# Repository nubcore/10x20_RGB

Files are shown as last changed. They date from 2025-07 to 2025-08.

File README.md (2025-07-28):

# 10x20_LED_screen
hardware design files and software applications for an esp32c3 + 200 "smart LEDs"  project.

## General

The PCB contains an ESP32-C3, 4 buttons and 200 ws2812B-like "smart LED" components that each contain three 256 level PWM controllers to drive the Red, Green and Blue LED channels. This means that each LED can theoretically display 2^24 colour combinations. The LEDs are supplied with the necessary data using a serial protocol, and are all connected in series in a single "string", so to drive all the LEDs, the ESP32-C3 must send 200 * 24 = 4800 bits of data. The LEDs need this data to be supplied at a net rate of 800,000 bits per second.
The actual low-level protocol used to transmit the data to the LEDs is as follows:

- ALL bits for a string of LEDs must be transmitted as a continuous stream immediately after a "reset pulse"
- A "0"-bit is transmitted as a 4 us high level, followed by an 8 us low level
- A "1"-bit is transmitted as an 8 us high level, followed by a 4 us low level
- After all bits have been transmitted, a 50 us low level serves as a "reset pulse"

This could be done using "bit-banging", but then the ESP can do little else aside. Alternatively, one can put one of the ESP32-C3's hardware peripherals to "alternative use".

## Hardware

The "hardware" folder contains the schematic diagram and KiCAD source files for this project.

__PLEASE NOTE THE FOLLOWING:__

This Do-It-Yourself project comes without any guarantee whatsoever.

5V Power should always be supplied to the LED portion DIRECTLY, NOT via the USB connector on the ESP32-C3 module.

It is, however, possible to supply the ESP32-C3 from the LED portion power supply by fitting a 0 Ohm resistor to R2. R2 should ONLY be fitted if you want to power the ESP32-C3 from the power supply connected to the LED portion, and it is then recommended to completely disconnect the USB cable and remove the USB connector from the ESP32-C3 module to prevent accidentally drawing power for the LED portion through the USB cable connected to the ESP32-C3 module.

Attempting to supply power through the USB connecter to the ESP32-C3 AND the LED portion may lead to damage to the ESP32-C3 module AND/OR to the USB power source. The LED portion alone can draw in excess of 1.5 A, and the ESP32-C3 module PCB traces and components are NOT rated for this. The LED portion does NOT properly negotiate its power draw with the power source by itself, and while the ESP32-C3 might be able to take on this task, there is no guarantee (given that users can run their own code on the ESP32-C3) that it will.

__TL;DR: Do not fit R2 unless you know what you are doing and willing to bear any and all consequences.__

## Software

The "software" folder contains some self-contained example Arduino applications. Two of these applications demonstrate the use of ESP32-C3's hardware peripherals to drive the display
.
### Driving the display with the "RMT" (remote control) perhipheral

The ledscreentest1 example demonstrates the use of the "RMT" perhipheral.Can generate very accurately timed signals, but has enormous memory overhead: it requires 32 times more storage than there is raw data to be sent to the LEDs. 24 bits to be sent to each LED requires 768 bits of memory. Every RGB byte translates to 8 32 bit word accesses. This method uses DMA (Direct memory access) to relieve the processor of these duties: The processor just needs to prepare a block of data and then start the transfer.

### Driving the display with the "SPI" (synchronous serial port) perhipheral 

The ledscreentest2 example demionstrates the use of the "SPI" perhipheral. Signals are less accuratly timed, but do actually work with the types of LEDs tested so far. Overhead is much lower than for the "RMT" method: it requires 4 times more storage than there is raw data to be sent to the LEDs. 24 bits to be sent to each LED requires 96 bits of memory. Moreover, as every (RGB) byte access becomes a single 32 bit word access, processor overhead is relatively limited. This method uses DMA (Direct memory access) to relieve the processor of these duties: The processor just needs to prepare a block of data and then start the transfer.

### "Famous-Falling-Block-Game"-tris

The blocktris example game uses 6 combinations of 2 buttons that are simultaneously pressed to control a falling block:

- start game
- move left
- move right
- turn clockwise
- turn counter-clockwise
- drop

Objective of the game is to score points by completely filling as many rows on the board as possible: 1 row = 1 point, 2 rows = 4 points, 3 rows = 9 points and 4 rows = 16 points. Completed rows are removed from the board, and the game ends when there is no more room for a new piece to spawn.

If you fill in the login credentials of an access point, the module will try to communicate a (global) high-score with a server.

### "Floppy brick"

Fly a brick, avoiding increasingly difficult obstacles along it's path by commanding it to flop using the "flop" button.

## Prerequisites

As Espressif regulary makes breaking changes to their API, it is important that you use the __correct version of the Espressif framework for Arduino: 3.1.3__

After you have installed the Espressif board manager package, you can __select the "ESP32-C3 Dev-module"__, which is compatible with the ESP32-C3 "super-mini" module that is usedin this project.

Please make sure that you have __set the option "USB CDC enable on boot" to "enabled"__ (Arduino tools menu), and that you have selected the correct serial device.

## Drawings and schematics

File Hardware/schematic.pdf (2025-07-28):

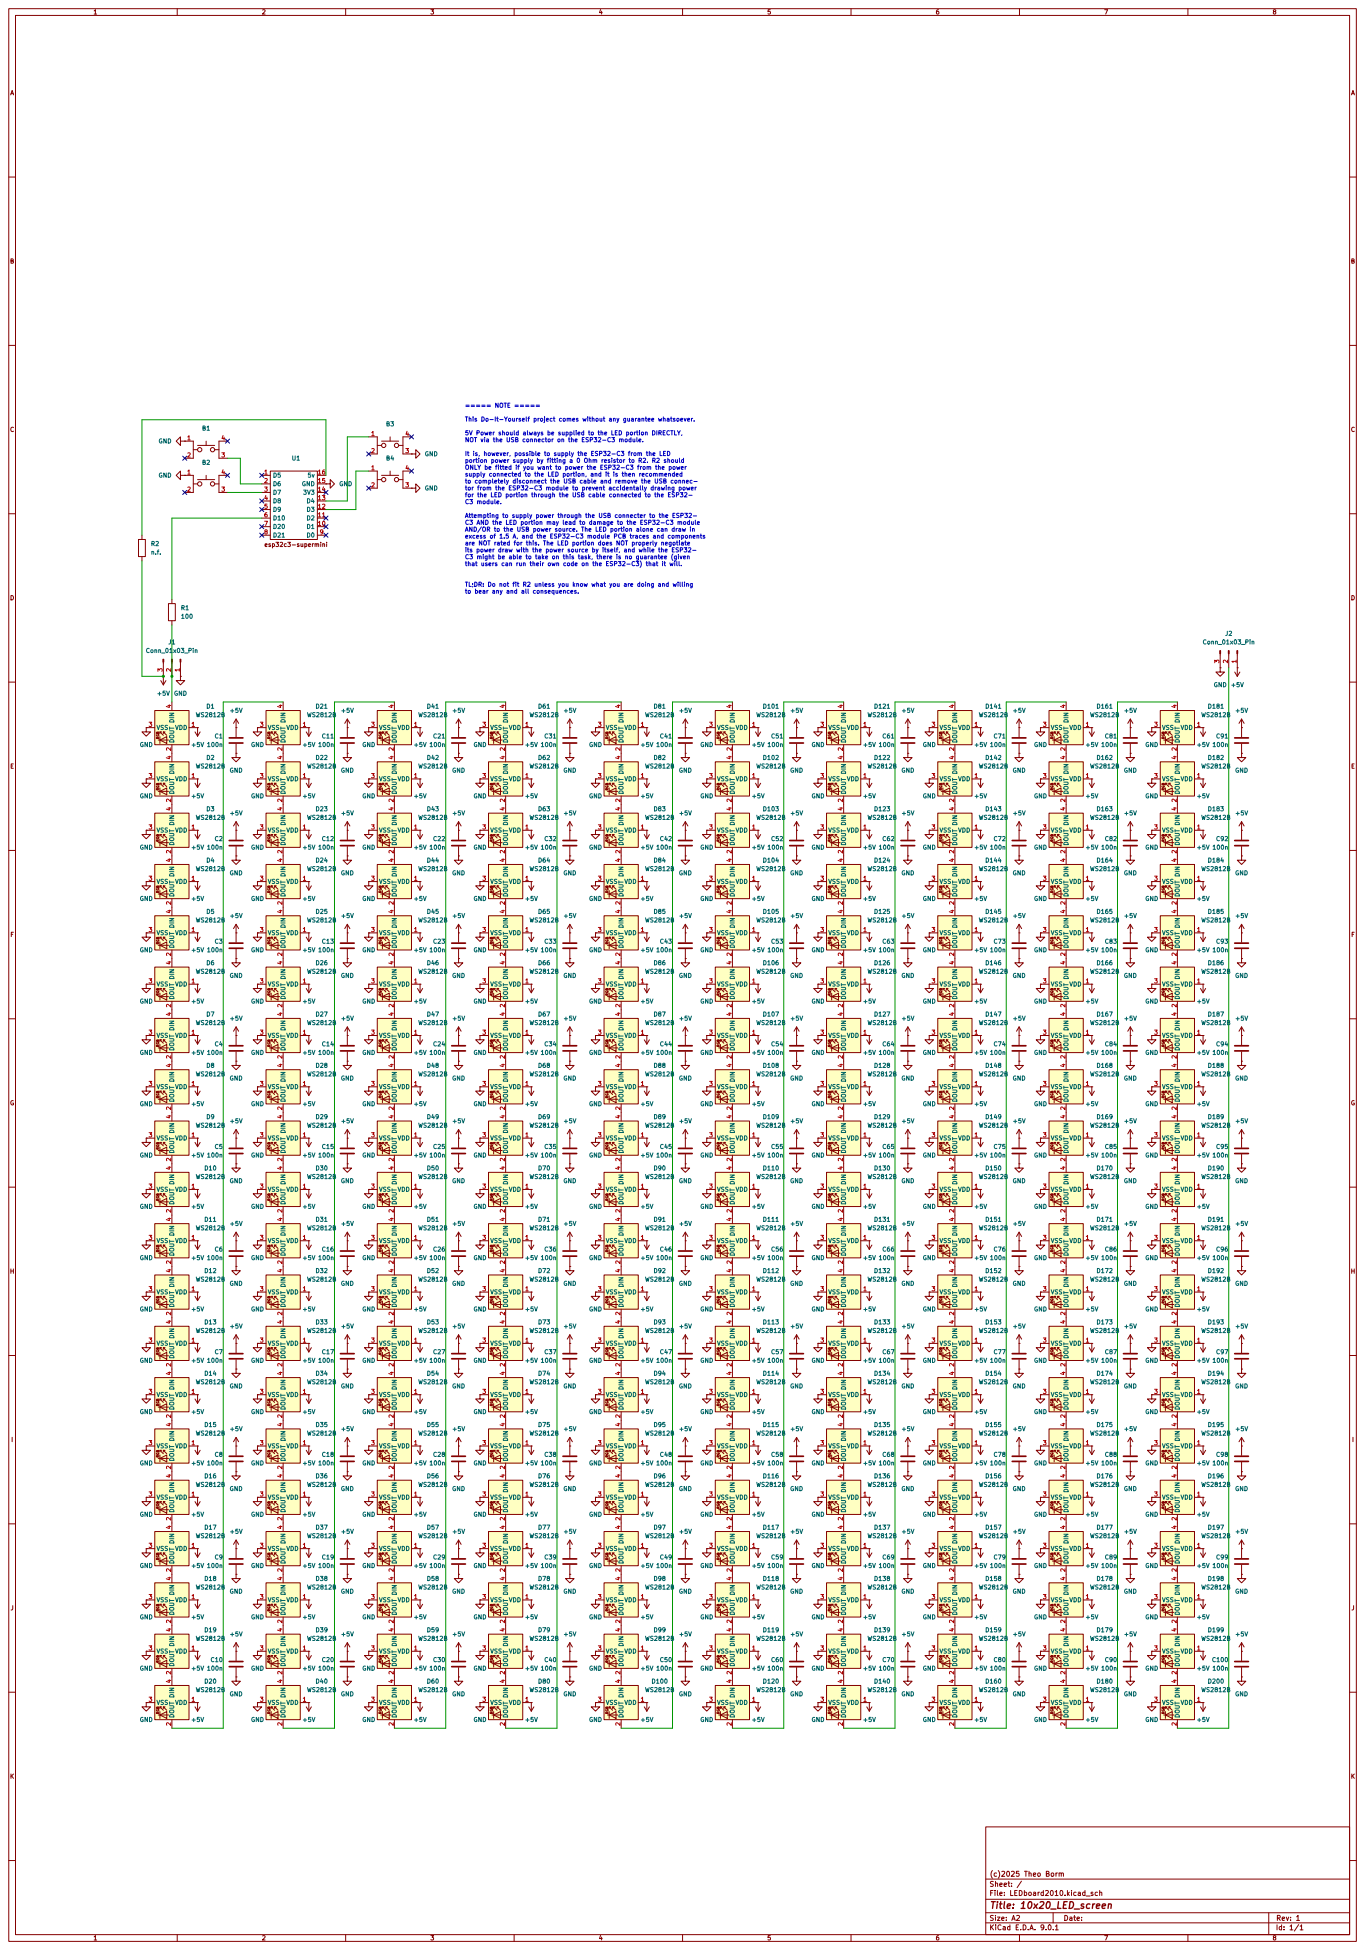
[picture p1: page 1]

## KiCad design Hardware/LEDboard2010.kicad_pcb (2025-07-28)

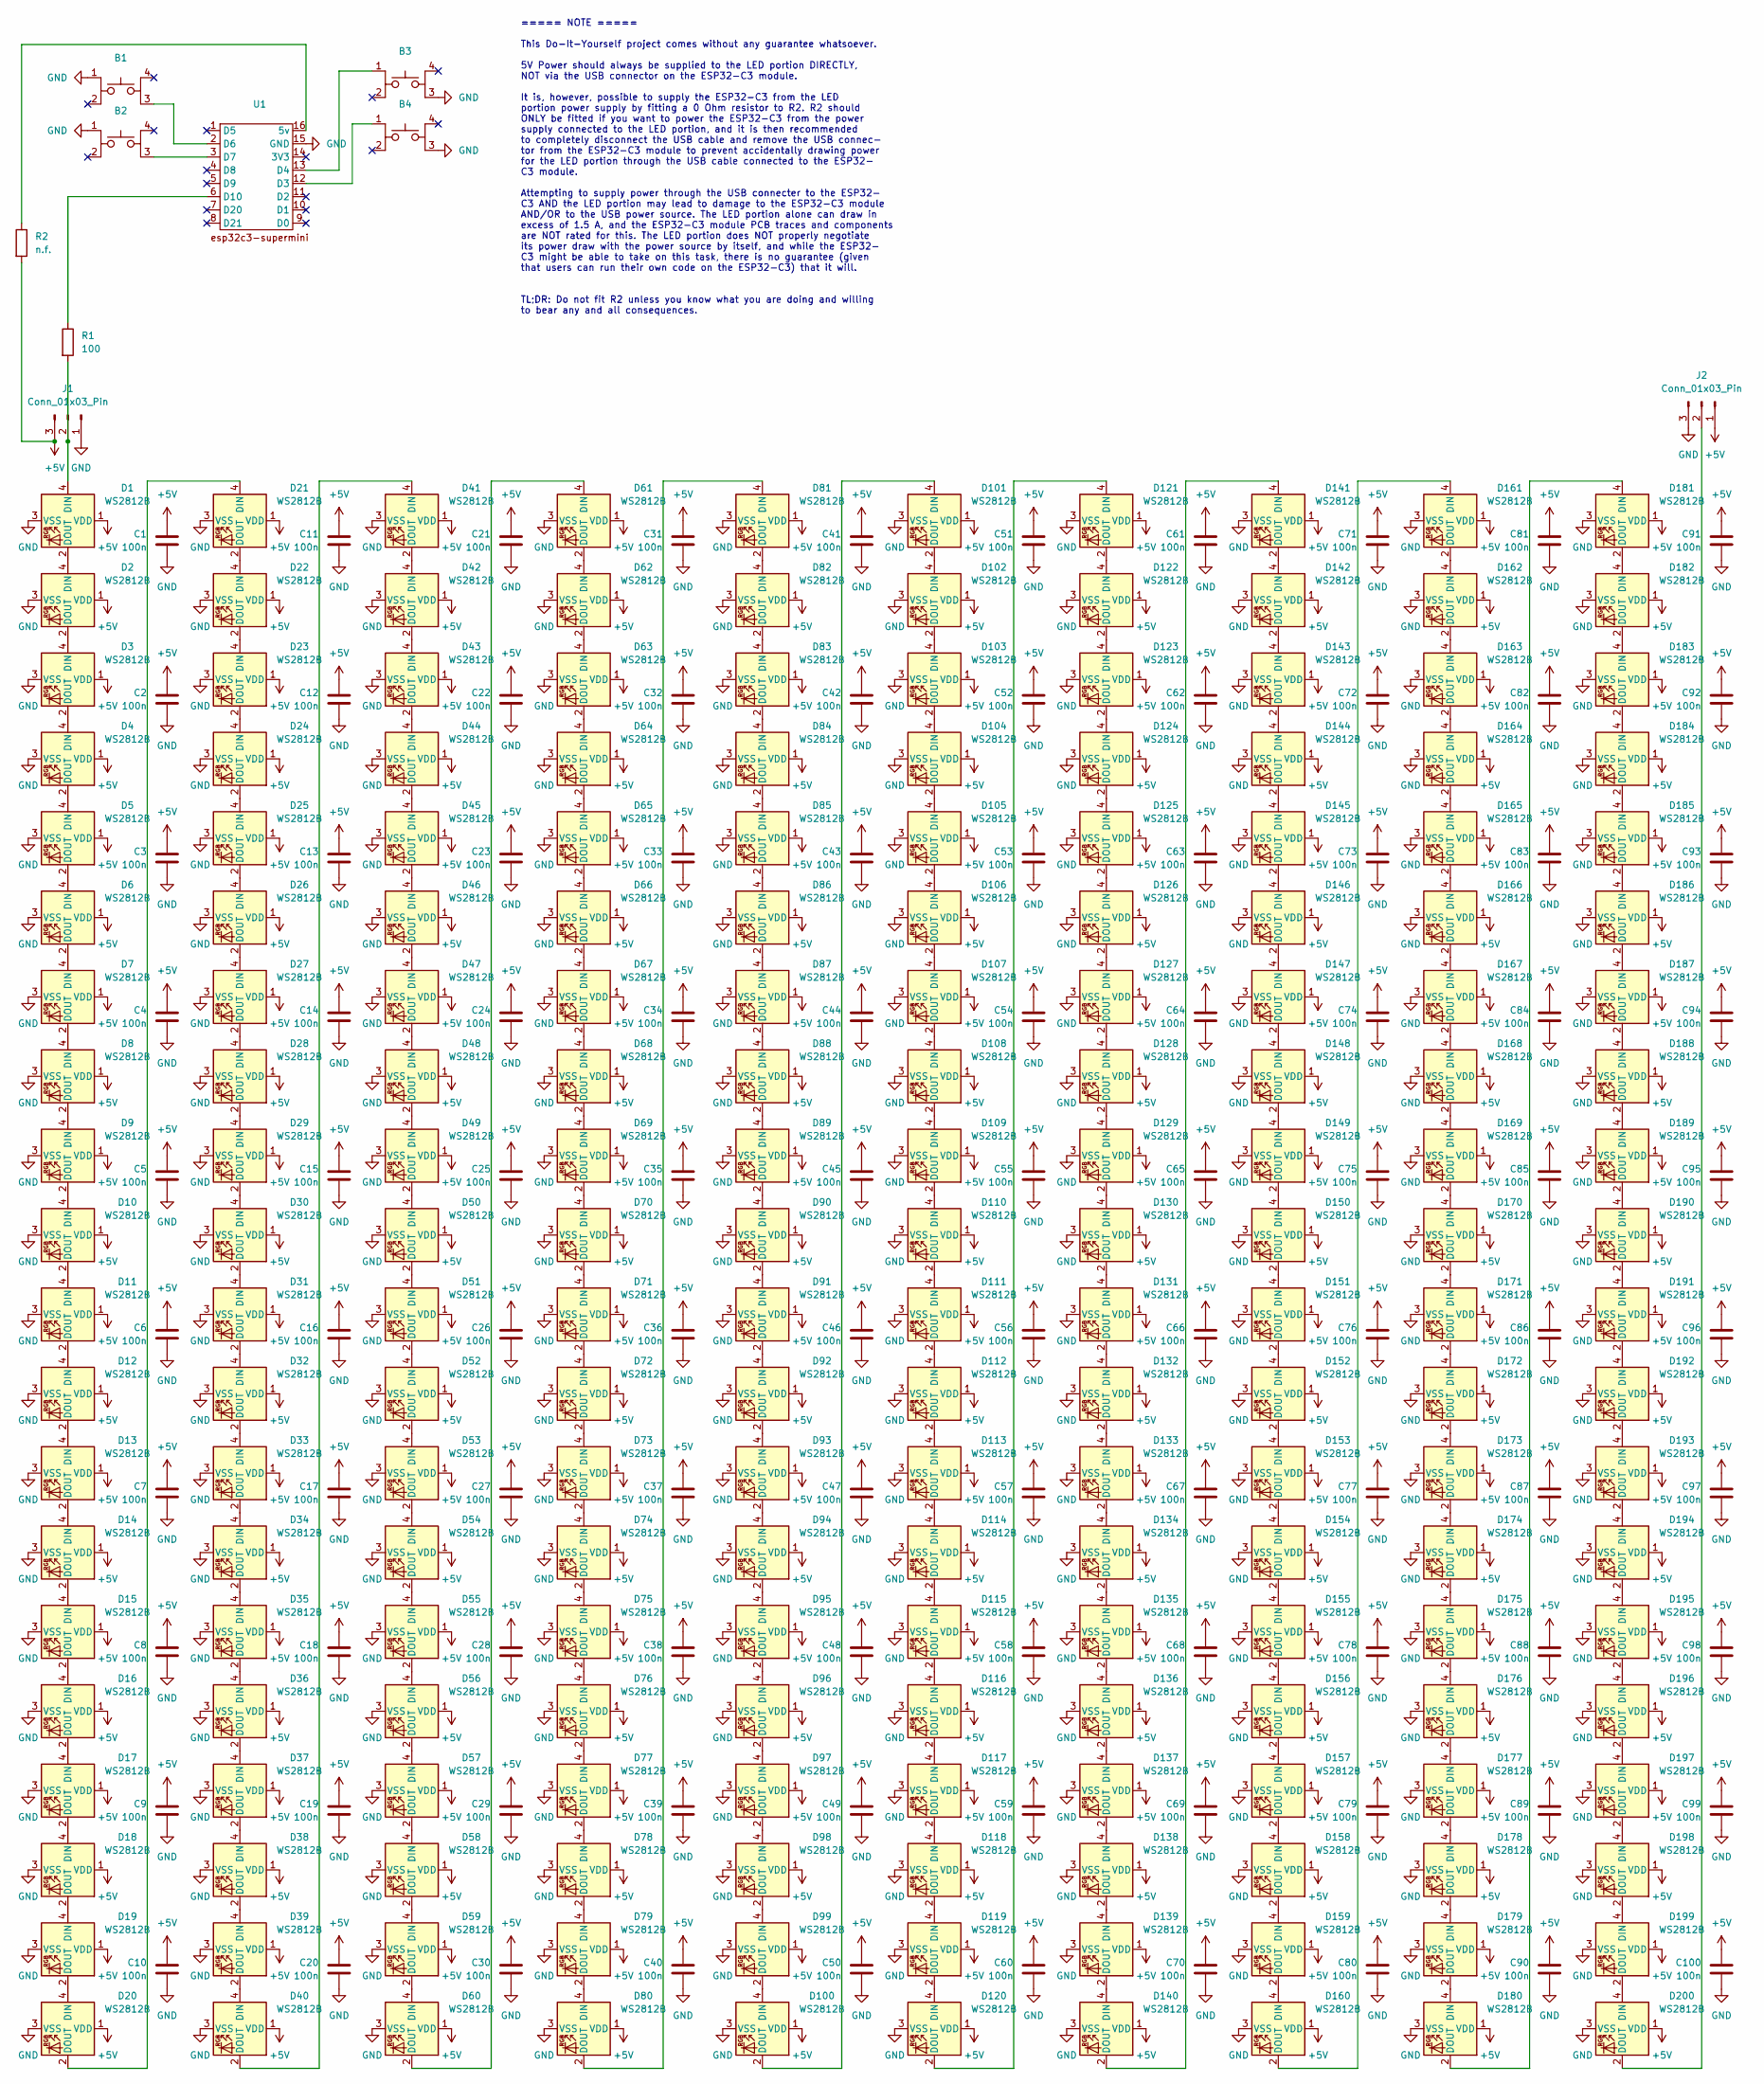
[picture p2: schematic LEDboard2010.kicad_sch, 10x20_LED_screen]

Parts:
B1, B2, B3, B4: button
C1, C2, C3, C4, C5, C6, C7, C8, C9, C10, C11, C12, C13, C14, C15, C16, C17, C18, C19, C20, C21, C22, C23, C24, C25, C26, C27, C28, C29, C30, C31, C32, C33, C34, C35, C36, C37, C38, C39, C40, C41, C42, C43, C44, C45, C46, C47, C48, C49, C50, C51, C52, C53, C54, C55, C56, C57, C58, C59, C60, C61, C62, C63, C64, C65, C66, C67, C68, C69, C70, C71, C72, C73, C74, C75, C76, C77, C78, C79, C80, C81, C82, C83, C84, C85, C86, C87, C88, C89, C90, C91, C92, C93, C94, C95, C96, C97, C98, C99, C100: 100n; C_0603
D1, D2, D3, D4, D5, D6, D7, D8, D9, D10, D11, D12, D13, D14, D15, D16, D17, D18, D19, D20, D21, D22, D23, D24, D25, D26, D27, D28, D29, D30, D31, D32, D33, D34, D35, D36, D37, D38, D39, D40, D41, D42, D43, D44, D45, D46, D47, D48, D49, D50, D51, D52, D53, D54, D55, D56, D57, D58, D59, D60, D61, D62, D63, D64, D65, D66, D67, D68, D69, D70, D71, D72, D73, D74, D75, D76, D77, D78, D79, D80, D81, D82, D83, D84, D85, D86, D87, D88, D89, D90, D91, D92, D93, D94, D95, D96, D97, D98, D99, D100, D101, D102, D103, D104, D105, D106, D107, D108, D109, D110, D111, D112, D113, D114, D115, D116, D117, D118, D119, D120, D121, D122, D123, D124, D125, D126, D127, D128, D129, D130, D131, D132, D133, D134, D135, D136, D137, D138, D139, D140, D141, D142, D143, D144, D145, D146, D147, D148, D149, D150, D151, D152, D153, D154, D155, D156, D157, D158, D159, D160, D161, D162, D163, D164, D165, D166, D167, D168, D169, D170, D171, D172, D173, D174, D175, D176, D177, D178, D179, D180, D181, D182, D183, D184, D185, D186, D187, D188, D189, D190, D191, D192, D193, D194, D195, D196, D197, D198, D199, D200: WS2812B; XINGLIGHT XL-0807RGBC-WS2812B-S
J1, J2: Conn_01x03_Pin; datacon
R1: 100; R_0805
R2: n.f.; R_0805
U1: esp32c3

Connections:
+5V: C1.2, C2.2, C3.2, C4.2, C5.2, C6.2, C7.2, C8.2, C9.2, C10.2, C11.2, C12.2, C13.2, C14.2, C15.2, C16.2, C17.2, C18.2, C19.2, C20.2, C21.2, C22.2, C23.2, C24.2, C25.2, C26.2, C27.2, C28.2, C29.2, C30.2, C31.2, C32.2, C33.2, C34.2, C35.2, C36.2, C37.2, C38.2, C39.2, C40.2, C41.2, C42.2, C43.2, C44.2, C45.2, C46.2, C47.2, C48.2, C49.2, C50.2, C51.2, C52.2, C53.2, C54.2, C55.2, C56.2, C57.2, C58.2, C59.2, C60.2, C61.2, C62.2, C63.2, C64.2, C65.2, C66.2, C67.2, C68.2, C69.2, C70.2, C71.2, C72.2, C73.2, C74.2, C75.2, C76.2, C77.2, C78.2, C79.2, C80.2, C81.2, C82.2, C83.2, C84.2, C85.2, C86.2, C87.2, C88.2, C89.2, C90.2, C91.2, C92.2, C93.2, C94.2, C95.2, C96.2, C97.2, C98.2, C99.2, C100.2, D1.1 (VDD), D2.1 (VDD), D3.1 (VDD), D4.1 (VDD), D5.1 (VDD), D6.1 (VDD), D7.1 (VDD), D8.1 (VDD), D9.1 (VDD), D10.1 (VDD), D11.1 (VDD), D12.1 (VDD), D13.1 (VDD), D14.1 (VDD), D15.1 (VDD), D16.1 (VDD), D17.1 (VDD), D18.1 (VDD), D19.1 (VDD), D20.1 (VDD), D21.1 (VDD), D22.1 (VDD), D23.1 (VDD), D24.1 (VDD), D25.1 (VDD), D26.1 (VDD), D27.1 (VDD), D28.1 (VDD), D29.1 (VDD), D30.1 (VDD), D31.1 (VDD), D32.1 (VDD), D33.1 (VDD), D34.1 (VDD), D35.1 (VDD), D36.1 (VDD), D37.1 (VDD), D38.1 (VDD), D39.1 (VDD), D40.1 (VDD), D41.1 (VDD), D42.1 (VDD), D43.1 (VDD), D44.1 (VDD), D45.1 (VDD), D46.1 (VDD), D47.1 (VDD), D48.1 (VDD), D49.1 (VDD), D50.1 (VDD), D51.1 (VDD), D52.1 (VDD), D53.1 (VDD), D54.1 (VDD), D55.1 (VDD), D56.1 (VDD), D57.1 (VDD), D58.1 (VDD), D59.1 (VDD), D60.1 (VDD), D61.1 (VDD), D62.1 (VDD), D63.1 (VDD), D64.1 (VDD), D65.1 (VDD), D66.1 (VDD), D67.1 (VDD), D68.1 (VDD), D69.1 (VDD), D70.1 (VDD), D71.1 (VDD), D72.1 (VDD), D73.1 (VDD), D74.1 (VDD), D75.1 (VDD), D76.1 (VDD), D77.1 (VDD), D78.1 (VDD), D79.1 (VDD), D80.1 (VDD), D81.1 (VDD), D82.1 (VDD), D83.1 (VDD), D84.1 (VDD), D85.1 (VDD), D86.1 (VDD), D87.1 (VDD), D88.1 (VDD), D89.1 (VDD), D90.1 (VDD), D91.1 (VDD), D92.1 (VDD), D93.1 (VDD), D94.1 (VDD), D95.1 (VDD), D96.1 (VDD), D97.1 (VDD), D98.1 (VDD), D99.1 (VDD), D100.1 (VDD), D101.1 (VDD), D102.1 (VDD), D103.1 (VDD), D104.1 (VDD), D105.1 (VDD), D106.1 (VDD), D107.1 (VDD), D108.1 (VDD), D109.1 (VDD), D110.1 (VDD), D111.1 (VDD), D112.1 (VDD), D113.1 (VDD), D114.1 (VDD), D115.1 (VDD), D116.1 (VDD), D117.1 (VDD), D118.1 (VDD), D119.1 (VDD), D120.1 (VDD), D121.1 (VDD), D122.1 (VDD), D123.1 (VDD), D124.1 (VDD), D125.1 (VDD), D126.1 (VDD), D127.1 (VDD), D128.1 (VDD), D129.1 (VDD), D130.1 (VDD), D131.1 (VDD), D132.1 (VDD), D133.1 (VDD), D134.1 (VDD), D135.1 (VDD), D136.1 (VDD), D137.1 (VDD), D138.1 (VDD), D139.1 (VDD), D140.1 (VDD), D141.1 (VDD), D142.1 (VDD), D143.1 (VDD), D144.1 (VDD), D145.1 (VDD), D146.1 (VDD), D147.1 (VDD), D148.1 (VDD), D149.1 (VDD), D150.1 (VDD), D151.1 (VDD), D152.1 (VDD), D153.1 (VDD), D154.1 (VDD), D155.1 (VDD), D156.1 (VDD), D157.1 (VDD), D158.1 (VDD), D159.1 (VDD), D160.1 (VDD), D161.1 (VDD), D162.1 (VDD), D163.1 (VDD), D164.1 (VDD), D165.1 (VDD), D166.1 (VDD), D167.1 (VDD), D168.1 (VDD), D169.1 (VDD), D170.1 (VDD), D171.1 (VDD), D172.1 (VDD), D173.1 (VDD), D174.1 (VDD), D175.1 (VDD), D176.1 (VDD), D177.1 (VDD), D178.1 (VDD), D179.1 (VDD), D180.1 (VDD), D181.1 (VDD), D182.1 (VDD), D183.1 (VDD), D184.1 (VDD), D185.1 (VDD), D186.1 (VDD), D187.1 (VDD), D188.1 (VDD), D189.1 (VDD), D190.1 (VDD), D191.1 (VDD), D192.1 (VDD), D193.1 (VDD), D194.1 (VDD), D195.1 (VDD), D196.1 (VDD), D197.1 (VDD), D198.1 (VDD), D199.1 (VDD), D200.1 (VDD), J1.3, J2.1, R2.2
GND: B1.1, B2.1, B3.3, B4.3, C1.1, C2.1, C3.1, C4.1, C5.1, C6.1, C7.1, C8.1, C9.1, C10.1, C11.1, C12.1, C13.1, C14.1, C15.1, C16.1, C17.1, C18.1, C19.1, C20.1, C21.1, C22.1, C23.1, C24.1, C25.1, C26.1, C27.1, C28.1, C29.1, C30.1, C31.1, C32.1, C33.1, C34.1, C35.1, C36.1, C37.1, C38.1, C39.1, C40.1, C41.1, C42.1, C43.1, C44.1, C45.1, C46.1, C47.1, C48.1, C49.1, C50.1, C51.1, C52.1, C53.1, C54.1, C55.1, C56.1, C57.1, C58.1, C59.1, C60.1, C61.1, C62.1, C63.1, C64.1, C65.1, C66.1, C67.1, C68.1, C69.1, C70.1, C71.1, C72.1, C73.1, C74.1, C75.1, C76.1, C77.1, C78.1, C79.1, C80.1, C81.1, C82.1, C83.1, C84.1, C85.1, C86.1, C87.1, C88.1, C89.1, C90.1, C91.1, C92.1, C93.1, C94.1, C95.1, C96.1, C97.1, C98.1, C99.1, C100.1, D1.3 (VSS), D2.3 (VSS), D3.3 (VSS), D4.3 (VSS), D5.3 (VSS), D6.3 (VSS), D7.3 (VSS), D8.3 (VSS), D9.3 (VSS), D10.3 (VSS), D11.3 (VSS), D12.3 (VSS), D13.3 (VSS), D14.3 (VSS), D15.3 (VSS), D16.3 (VSS), D17.3 (VSS), D18.3 (VSS), D19.3 (VSS), D20.3 (VSS), D21.3 (VSS), D22.3 (VSS), D23.3 (VSS), D24.3 (VSS), D25.3 (VSS), D26.3 (VSS), D27.3 (VSS), D28.3 (VSS), D29.3 (VSS), D30.3 (VSS), D31.3 (VSS), D32.3 (VSS), D33.3 (VSS), D34.3 (VSS), D35.3 (VSS), D36.3 (VSS), D37.3 (VSS), D38.3 (VSS), D39.3 (VSS), D40.3 (VSS), D41.3 (VSS), D42.3 (VSS), D43.3 (VSS), D44.3 (VSS), D45.3 (VSS), D46.3 (VSS), D47.3 (VSS), D48.3 (VSS), D49.3 (VSS), D50.3 (VSS), D51.3 (VSS), D52.3 (VSS), D53.3 (VSS), D54.3 (VSS), D55.3 (VSS), D56.3 (VSS), D57.3 (VSS), D58.3 (VSS), D59.3 (VSS), D60.3 (VSS), D61.3 (VSS), D62.3 (VSS), D63.3 (VSS), D64.3 (VSS), D65.3 (VSS), D66.3 (VSS), D67.3 (VSS), D68.3 (VSS), D69.3 (VSS), D70.3 (VSS), D71.3 (VSS), D72.3 (VSS), D73.3 (VSS), D74.3 (VSS), D75.3 (VSS), D76.3 (VSS), D77.3 (VSS), D78.3 (VSS), D79.3 (VSS), D80.3 (VSS), D81.3 (VSS), D82.3 (VSS), D83.3 (VSS), D84.3 (VSS), D85.3 (VSS), D86.3 (VSS), D87.3 (VSS), D88.3 (VSS), D89.3 (VSS), D90.3 (VSS), D91.3 (VSS), D92.3 (VSS), D93.3 (VSS), D94.3 (VSS), D95.3 (VSS), D96.3 (VSS), D97.3 (VSS), D98.3 (VSS), D99.3 (VSS), D100.3 (VSS), D101.3 (VSS), D102.3 (VSS), D103.3 (VSS), D104.3 (VSS), D105.3 (VSS), D106.3 (VSS), D107.3 (VSS), D108.3 (VSS), D109.3 (VSS), D110.3 (VSS), D111.3 (VSS), D112.3 (VSS), D113.3 (VSS), D114.3 (VSS), D115.3 (VSS), D116.3 (VSS), D117.3 (VSS), D118.3 (VSS), D119.3 (VSS), D120.3 (VSS), D121.3 (VSS), D122.3 (VSS), D123.3 (VSS), D124.3 (VSS), D125.3 (VSS), D126.3 (VSS), D127.3 (VSS), D128.3 (VSS), D129.3 (VSS), D130.3 (VSS), D131.3 (VSS), D132.3 (VSS), D133.3 (VSS), D134.3 (VSS), D135.3 (VSS), D136.3 (VSS), D137.3 (VSS), D138.3 (VSS), D139.3 (VSS), D140.3 (VSS), D141.3 (VSS), D142.3 (VSS), D143.3 (VSS), D144.3 (VSS), D145.3 (VSS), D146.3 (VSS), D147.3 (VSS), D148.3 (VSS), D149.3 (VSS), D150.3 (VSS), D151.3 (VSS), D152.3 (VSS), D153.3 (VSS), D154.3 (VSS), D155.3 (VSS), D156.3 (VSS), D157.3 (VSS), D158.3 (VSS), D159.3 (VSS), D160.3 (VSS), D161.3 (VSS), D162.3 (VSS), D163.3 (VSS), D164.3 (VSS), D165.3 (VSS), D166.3 (VSS), D167.3 (VSS), D168.3 (VSS), D169.3 (VSS), D170.3 (VSS), D171.3 (VSS), D172.3 (VSS), D173.3 (VSS), D174.3 (VSS), D175.3 (VSS), D176.3 (VSS), D177.3 (VSS), D178.3 (VSS), D179.3 (VSS), D180.3 (VSS), D181.3 (VSS), D182.3 (VSS), D183.3 (VSS), D184.3 (VSS), D185.3 (VSS), D186.3 (VSS), D187.3 (VSS), D188.3 (VSS), D189.3 (VSS), D190.3 (VSS), D191.3 (VSS), D192.3 (VSS), D193.3 (VSS), D194.3 (VSS), D195.3 (VSS), D196.3 (VSS), D197.3 (VSS), D198.3 (VSS), D199.3 (VSS), D200.3 (VSS), J1.1, J2.3, U1.15 (GND)
unnamed: D1.4 (DIN), J1.2, R1.2
unnamed: D1.2 (DOUT), D2.4 (DIN)
unnamed: D2.2 (DOUT), D3.4 (DIN)
unnamed: D3.2 (DOUT), D4.4 (DIN)
unnamed: D4.2 (DOUT), D5.4 (DIN)
unnamed: D5.2 (DOUT), D6.4 (DIN)
unnamed: D6.2 (DOUT), D7.4 (DIN)
unnamed: D7.2 (DOUT), D8.4 (DIN)
unnamed: D8.2 (DOUT), D9.4 (DIN)
unnamed: D9.2 (DOUT), D10.4 (DIN)
unnamed: D10.2 (DOUT), D11.4 (DIN)
unnamed: D11.2 (DOUT), D12.4 (DIN)
unnamed: D12.2 (DOUT), D13.4 (DIN)
unnamed: D13.2 (DOUT), D14.4 (DIN)
unnamed: D14.2 (DOUT), D15.4 (DIN)
unnamed: D15.2 (DOUT), D16.4 (DIN)
unnamed: D16.2 (DOUT), D17.4 (DIN)
unnamed: D17.2 (DOUT), D18.4 (DIN)
unnamed: D18.2 (DOUT), D19.4 (DIN)
unnamed: D19.2 (DOUT), D20.4 (DIN)
unnamed: D20.2 (DOUT), D21.4 (DIN)
unnamed: D21.2 (DOUT), D22.4 (DIN)
unnamed: D22.2 (DOUT), D23.4 (DIN)
unnamed: D23.2 (DOUT), D24.4 (DIN)
unnamed: D24.2 (DOUT), D25.4 (DIN)
unnamed: D25.2 (DOUT), D26.4 (DIN)
unnamed: D26.2 (DOUT), D27.4 (DIN)
unnamed: D27.2 (DOUT), D28.4 (DIN)
unnamed: D28.2 (DOUT), D29.4 (DIN)
unnamed: D29.2 (DOUT), D30.4 (DIN)
unnamed: D30.2 (DOUT), D31.4 (DIN)
unnamed: D31.2 (DOUT), D32.4 (DIN)
unnamed: D32.2 (DOUT), D33.4 (DIN)
unnamed: D33.2 (DOUT), D34.4 (DIN)
unnamed: D34.2 (DOUT), D35.4 (DIN)
unnamed: D35.2 (DOUT), D36.4 (DIN)
unnamed: D36.2 (DOUT), D37.4 (DIN)
unnamed: D37.2 (DOUT), D38.4 (DIN)
unnamed: D38.2 (DOUT), D39.4 (DIN)
unnamed: D39.2 (DOUT), D40.4 (DIN)
unnamed: D40.2 (DOUT), D41.4 (DIN)
unnamed: D41.2 (DOUT), D42.4 (DIN)
unnamed: D42.2 (DOUT), D43.4 (DIN)
unnamed: D43.2 (DOUT), D44.4 (DIN)
unnamed: D44.2 (DOUT), D45.4 (DIN)
unnamed: D45.2 (DOUT), D46.4 (DIN)
unnamed: D46.2 (DOUT), D47.4 (DIN)
unnamed: D47.2 (DOUT), D48.4 (DIN)
unnamed: D48.2 (DOUT), D49.4 (DIN)
unnamed: D49.2 (DOUT), D50.4 (DIN)
unnamed: D50.2 (DOUT), D51.4 (DIN)
unnamed: D51.2 (DOUT), D52.4 (DIN)
unnamed: D52.2 (DOUT), D53.4 (DIN)
unnamed: D53.2 (DOUT), D54.4 (DIN)
unnamed: D54.2 (DOUT), D55.4 (DIN)
unnamed: D55.2 (DOUT), D56.4 (DIN)
unnamed: D56.2 (DOUT), D57.4 (DIN)
unnamed: D57.2 (DOUT), D58.4 (DIN)
unnamed: D58.2 (DOUT), D59.4 (DIN)
unnamed: D59.2 (DOUT), D60.4 (DIN)
unnamed: D60.2 (DOUT), D61.4 (DIN)
unnamed: D61.2 (DOUT), D62.4 (DIN)
unnamed: D62.2 (DOUT), D63.4 (DIN)
unnamed: D63.2 (DOUT), D64.4 (DIN)
unnamed: D64.2 (DOUT), D65.4 (DIN)
unnamed: D65.2 (DOUT), D66.4 (DIN)
unnamed: D66.2 (DOUT), D67.4 (DIN)
unnamed: D67.2 (DOUT), D68.4 (DIN)
unnamed: D68.2 (DOUT), D69.4 (DIN)
unnamed: D69.2 (DOUT), D70.4 (DIN)
unnamed: D70.2 (DOUT), D71.4 (DIN)
unnamed: D71.2 (DOUT), D72.4 (DIN)
unnamed: D72.2 (DOUT), D73.4 (DIN)
unnamed: D73.2 (DOUT), D74.4 (DIN)
unnamed: D74.2 (DOUT), D75.4 (DIN)
unnamed: D75.2 (DOUT), D76.4 (DIN)
unnamed: D76.2 (DOUT), D77.4 (DIN)
unnamed: D77.2 (DOUT), D78.4 (DIN)
unnamed: D78.2 (DOUT), D79.4 (DIN)
unnamed: D79.2 (DOUT), D80.4 (DIN)
unnamed: D80.2 (DOUT), D81.4 (DIN)
unnamed: D81.2 (DOUT), D82.4 (DIN)
unnamed: D82.2 (DOUT), D83.4 (DIN)
unnamed: D83.2 (DOUT), D84.4 (DIN)
unnamed: D84.2 (DOUT), D85.4 (DIN)
unnamed: D85.2 (DOUT), D86.4 (DIN)
unnamed: D86.2 (DOUT), D87.4 (DIN)
unnamed: D87.2 (DOUT), D88.4 (DIN)
unnamed: D88.2 (DOUT), D89.4 (DIN)
unnamed: D89.2 (DOUT), D90.4 (DIN)
unnamed: D90.2 (DOUT), D91.4 (DIN)
unnamed: D91.2 (DOUT), D92.4 (DIN)
unnamed: D92.2 (DOUT), D93.4 (DIN)
unnamed: D93.2 (DOUT), D94.4 (DIN)
unnamed: D94.2 (DOUT), D95.4 (DIN)
unnamed: D95.2 (DOUT), D96.4 (DIN)
unnamed: D96.2 (DOUT), D97.4 (DIN)
unnamed: D97.2 (DOUT), D98.4 (DIN)
unnamed: D98.2 (DOUT), D99.4 (DIN)
unnamed: D99.2 (DOUT), D100.4 (DIN)
unnamed: D100.2 (DOUT), D101.4 (DIN)
unnamed: D101.2 (DOUT), D102.4 (DIN)
unnamed: D102.2 (DOUT), D103.4 (DIN)
unnamed: D103.2 (DOUT), D104.4 (DIN)
unnamed: D104.2 (DOUT), D105.4 (DIN)
unnamed: D105.2 (DOUT), D106.4 (DIN)
unnamed: D106.2 (DOUT), D107.4 (DIN)
unnamed: D107.2 (DOUT), D108.4 (DIN)
unnamed: D108.2 (DOUT), D109.4 (DIN)
unnamed: D109.2 (DOUT), D110.4 (DIN)
unnamed: D110.2 (DOUT), D111.4 (DIN)
unnamed: D111.2 (DOUT), D112.4 (DIN)
unnamed: D112.2 (DOUT), D113.4 (DIN)
unnamed: D113.2 (DOUT), D114.4 (DIN)
unnamed: D114.2 (DOUT), D115.4 (DIN)
unnamed: D115.2 (DOUT), D116.4 (DIN)
unnamed: D116.2 (DOUT), D117.4 (DIN)
unnamed: D117.2 (DOUT), D118.4 (DIN)
unnamed: D118.2 (DOUT), D119.4 (DIN)
unnamed: D119.2 (DOUT), D120.4 (DIN)
unnamed: D120.2 (DOUT), D121.4 (DIN)
unnamed: D121.2 (DOUT), D122.4 (DIN)
unnamed: D122.2 (DOUT), D123.4 (DIN)
unnamed: D123.2 (DOUT), D124.4 (DIN)
unnamed: D124.2 (DOUT), D125.4 (DIN)
unnamed: D125.2 (DOUT), D126.4 (DIN)
unnamed: D126.2 (DOUT), D127.4 (DIN)
unnamed: D127.2 (DOUT), D128.4 (DIN)
unnamed: D128.2 (DOUT), D129.4 (DIN)
unnamed: D129.2 (DOUT), D130.4 (DIN)
unnamed: D130.2 (DOUT), D131.4 (DIN)
unnamed: D131.2 (DOUT), D132.4 (DIN)
unnamed: D132.2 (DOUT), D133.4 (DIN)
unnamed: D133.2 (DOUT), D134.4 (DIN)
unnamed: D134.2 (DOUT), D135.4 (DIN)
unnamed: D135.2 (DOUT), D136.4 (DIN)
unnamed: D136.2 (DOUT), D137.4 (DIN)
unnamed: D137.2 (DOUT), D138.4 (DIN)
unnamed: D138.2 (DOUT), D139.4 (DIN)
unnamed: D139.2 (DOUT), D140.4 (DIN)
unnamed: D140.2 (DOUT), D141.4 (DIN)
unnamed: D141.2 (DOUT), D142.4 (DIN)
unnamed: D142.2 (DOUT), D143.4 (DIN)
unnamed: D143.2 (DOUT), D144.4 (DIN)
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

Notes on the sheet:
===== NOTE ===== This Do-It-Yourself project comes without any guarantee whatsoever. 5V Power should always be supplied to the LED portion DIRECTLY, NOT via the USB connector on the ESP32-C3 module. It is, however, possible to supply the ESP32-C3 from the LED portion power supply by fitting a 0 Ohm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

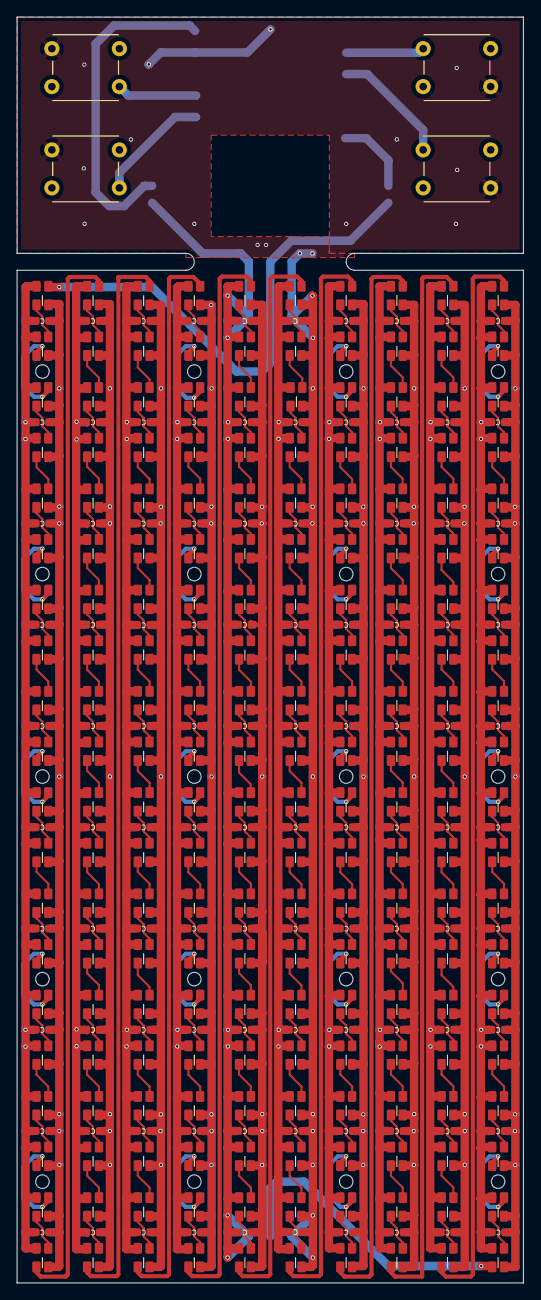
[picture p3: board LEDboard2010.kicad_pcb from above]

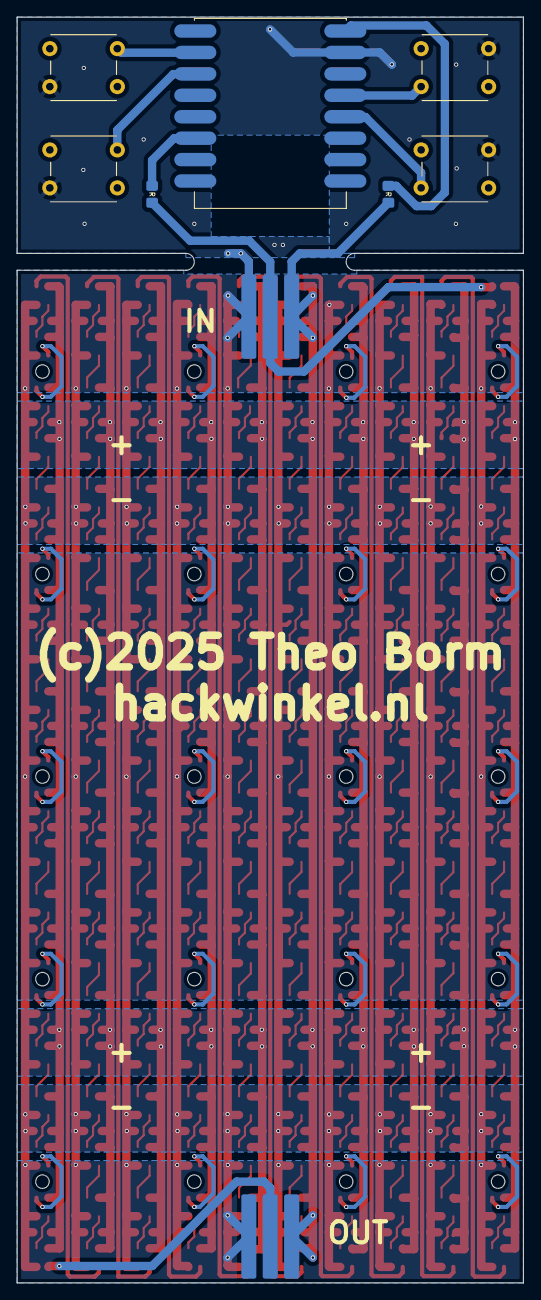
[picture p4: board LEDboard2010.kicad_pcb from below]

Board: 2 copper layers, 60.0 x 150.0 mm, 309 parts (5 on the bottom side), 209 nets.

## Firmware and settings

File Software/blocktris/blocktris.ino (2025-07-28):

/**********************************************************************************
 * Copyright (c) 2025, Theo Borm
 * 
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
 * 3. Neither the name of the copyright holder nor the names of its
 *    contributors may be used to endorse or promote products derived from
 *    this software without specific prior written permission.
 *
 * THIS SOFTWARE IS PROVIDED BY THE COPYRIGHT HOLDERS AND CONTRIBUTORS "AS IS"
 * AND ANY EXPRESS OR IMPLIED WARRANTIES, INCLUDING, BUT NOT LIMITED TO, THE
 * IMPLIED WARRANTIES OF MERCHANTABILITY AND FITNESS FOR A PARTICULAR PURPOSE ARE
 * DISCLAIMED. IN NO EVENT SHALL THE COPYRIGHT HOLDER OR CONTRIBUTORS BE LIABLE
 * FOR ANY DIRECT, INDIRECT, INCIDENTAL, SPECIAL, EXEMPLARY, OR CONSEQUENTIAL
 * DAMAGES (INCLUDING, BUT NOT LIMITED TO, PROCUREMENT OF SUBSTITUTE GOODS OR
 * SERVICES; LOSS OF USE, DATA, OR PROFITS; OR BUSINESS INTERRUPTION) HOWEVER
 * CAUSED AND ON ANY THEORY OF LIABILITY, WHETHER IN CONTRACT, STRICT LIABILITY,
 * OR TORT (INCLUDING NEGLIGENCE OR OTHERWISE) ARISING IN ANY WAY OUT OF THE USE
 * OF THIS SOFTWARE, EVEN IF ADVISED OF THE POSSIBILITY OF SUCH DAMAGE.
 */

#define ACCESSPOINTSSID "bornhack"
#define ACCESSPOINTPASSWORD ""

/*******************************************************************************************************************
* Arduino sucks.
*
* Really, The Arduino IDE is a multi-level clusterfuck for everything but the simplest projects.
*
* This could (or maybe should) be a multi-page rant about what is wrong with ARDUINO, and there
* might be some entertainment value in that, but I simply don't have the time for it, so I'll
* be short.
*
* There is NO project management in ARDUINO, and if you split source across multiple files
* you end up in dependency hell because the ARDUINO IDE breaks C/C++ programming standards.
* Splitting complex source into multiple units along functional bounfaries is a way to keep
* code understandable and manageable, and is something programmers deal with on a daily basis.
* Not in ARDUINO IDE, though. The ARDUINO IDE adds some "Magic" to the compilation process which
* (I guess) makes it slightly easier to get started, but which breaks normal dependency management.
*
* While it may very well be possible to work around the limitations and create a multi-source-
* file project, with sources split in a way that makes some sense from a software maintainance
* point of view, I simply don't have the time nor energy to jump through these hoops, So I
* restructured everything so that it at least works: one big file. As a convenience I've split
* the code into "functional sections" with markers on the boundaries.
*
*******************************************************************************************************************/


/*******************************************************************************************************************
* INCLUDES section for external header files
*******************************************************************************************************************/
#include <Arduino.h>
#include <stdint.h>
#include <stdio.h>
#include <string.h>
#include "driver/spi_master.h"
#include "driver/gpio.h"
#include "esp_heap_caps.h"
// for high score server
#include <WiFi.h>
#include <HTTPClient.h>

/*******************************************************************************************************************
* TYPEDEFINITIONS section here because ARDUINO IDE does weird stuff with them
*******************************************************************************************************************/
// a struct holding the 3 32 bit encoded colour values in the required order
typedef struct {
  uint32_t G;
  uint32_t R;
  uint32_t B;
} paletteColour;

// a shape has a type, orientation and a position. the natural color of a shape is t * 2 (+1 for bright)
typedef struct {
  int8_t t;
  int8_t r;
  int8_t x;
  int8_t y;
} shape;

// when rotating pieces, they can sometimes be "kicked" into a different position
typedef struct {
  int8_t x;
  int8_t y;
} kick;

/*******************************************************************************************************************
* BOARDSUPPORT section
*******************************************************************************************************************/
// some basic stuff for working (only) with boards. Depends on nothing internally, but other sections depend on this.
#define BOARDWIDTH 10
#define BOARDHEIGHT 20
#define SPAWNHEIGHT 5

// the "board" on which we play. "spawn" area is above the play area, and is  invisible
uint8_t board[BOARDHEIGHT+SPAWNHEIGHT][BOARDWIDTH]; // spawn area = rows above board

// returns true or false if a row is completely full or not
int8_t isBoardRowFull(uint8_t y) {
  for (int8_t x=0; x<BOARDWIDTH; x++) {
    if (board[y][x] <= 1) return(0); //no
  }
  return(1); // yes
}

// returns the index of the first full row from the bottom, or -1 if there is none
int8_t findFirstFullRow(void) {
  for (int8_t i=0; i<BOARDHEIGHT+SPAWNHEIGHT; i++) {
    if (isBoardRowFull(i)) return(i);
  }
  return(-1); // no full row
}

// returns the end (+1) of a block of full rows from the bottom given a starting row.
int8_t findLastFullRowInBlock(int8_t sr) { 
  for (int8_t i=sr+1; i<BOARDHEIGHT+SPAWNHEIGHT; i++) {
    if (isBoardRowFull(i)==0) return(i); // not full, so previous line was last
  }
  return(BOARDHEIGHT+SPAWNHEIGHT);
}

/*******************************************************************************************************************
* PALETTESUPPORT section
*******************************************************************************************************************/
// some basic stuff for working (only) with palettes translating indexed colour values into encoded values to be
// sent to the WS2812 string. Depends on nothing internally, but other sections depend on this.

void mangle(paletteColour * p){
  p->B=0xf0f0f0f0;
}
// a standard palette with 18 colours
paletteColour standardPalette[18]= {
  {//black
    0b10001000100010001000100010001000,
    0b10001000100010001000100010001000,
    0b10001000100010001000100010001000
  },{//dark grey
    0b10001110100010001000100010001000,
    0b10001110100010001000100010001000,
    0b10001110100010001000100010001000
  },{// cyan
    0b10001000100010001110100010001000,
    0b10001000100010001000100010001000,
    0b10001000100010001110100010001000
  },{//light cyan
    0b10001000100010001000100010001110,
    0b10001000100010001000100010001000,
    0b10001000100010001000100010001110
  },{//yellow
    0b10001000100010001110100010001000,
    0b10001000100010001000111010001000,
    0b10001000100010001000100010001000,
  },{//light yellow
    0b10001000100010001000100010001110,
    0b10001000100010001110100010001000,
    0b10001000100010001000100010001000
  },{//magenta
    0b10001000100010001000100010001000,
    0b10001000100010001110100010001000,
    0b10001000100010001110100010001000
  },{//light magenta
    0b10001000100010001000100010001000,
    0b10001000100010001000100010001110,
    0b10001000100010001000100010001110
  },{//orange
    0b10001000100011101000100010001000,
    0b10001000100010001110100010001000,
    0b10001000100010001000100010001000
  },{//light orange
    0b10001000100010001110100010001000,
    0b10001000100010001000100010001110,
    0b10001000100010001000100010001000
  },{//blue
    0b10001000100010001000100010001000,
    0b10001000100010001000100010001000,
    0b10001000100010001110100010001000
  },{//light blue
    0b10001000100010001000100010001000,
    0b10001000100010001000100010001000,
    0b10001000100010001000100010001110
  },{//green
    0b10001000100010001110100010001000,
    0b10001000100010001000100010001000,
    0b10001000100010001000100010001000
  },{//light green
    0b10001000100010001000100010001110,
    0b10001000100010001000100010001000,
    0b10001000100010001000100010001000
  },{//red
    0b10001000100010001000100010001000,
    0b10001000100010001110100010001000,
    0b10001000100010001000100010001000
  },{//light red
    0b10001000100010001000100010001000,
    0b10001000100010001000100010001110,
    0b10001000100010001000100010001000
  },{//light grey
    0b10001000111010001000100010001000,
    0b10001000111010001000100010001000,
    0b10001000111010001000100010001000
  },{// white
    0b10001000100010001000100010001110,
    0b10001000100010001000100010001110,
    0b10001000100010001000100010001110
  }
};

// Encode an 8 bit value into a 32 bit value
uint32_t SpiLedScreenEncodeValue(uint8_t v) {
  uint32_t r=0b10001000100010001000100010001000; //encoding of all zero bits
  if (v&  1) r |= 0b10001110100010001000100010001000;
  if (v&  2) r |= 0b11101000100010001000100010001000;
  if (v&  4) r |= 0b10001000100011101000100010001000;
  if (v&  8) r |= 0b10001000111010001000100010001000;
  if (v& 16) r |= 0b10001000100010001000111010001000;
  if (v& 32) r |= 0b10001000100010001110100010001000;
  if (v& 64) r |= 0b10001000100010001000100010001110;
  if (v&128) r |= 0b10001000100010001000100011101000;
  return(r);
 }

 // fill a single palette entry with the appropriate requested value
  void SpiLedScreenCreateColour(paletteColour * p, uint8_t R, uint8_t G, uint8_t B) {
  /*
    p->R=SpiLedScreenEncodeValue(R);
    p->G=SpiLedScreenEncodeValue(G);
    p->B=SpiLedScreenEncodeValue(B);
    */
 }


/*******************************************************************************************************************
* SPILEDSCREEN section
*******************************************************************************************************************/
// basic SPI+DMA hardware LED screen driver. Depends on PALETTESUPPORT internally, but other sections depend on this.
/*
 * This code uses SPI to send data to the ws2812 LED panel(s).
 * The WS2812 expects each bit to last ~ 1.2 us. A "1" is transmitted as an 800ns
 * high level on a pin, followed by a 400ns low level. A "0" is transmitted as a 400ns
 * high level on a pin, followed by an 800ns low level. The data rate is 800 kbit/s
 * If we operate the SPI at 3.2 MHz, we can "emulate" this on-off pattern with 4 bits
 * per bit that must be sent to the panel. A "0" bit is emulated using the pattern
 * 1000, a "1" bit is emulated using the pattern 1110. This means that a "0" bit is
 * sent as a 312.5 ns high, followed by a 937.5 ns low signal, and that a "1" bit is
 * sent as a 837.5 ns high, followed by a 312.5 ns low signal. This is OFF-SPEC, but
 * it works. Main benefit is that one byte of data to be transmitted fits into a 32
 * bit pattern, using "only" 4 times more memory than the "real" data, as opposed to
 * 32 times as much data for the RMT perhipheral. This also makes manipulating
 * display data much more efficient. Instead of shifting colour bits and then turning
 * colour bits into 32 bits in memory, we can write a (translated) colour byte to
 * memory as a single 32 bit word.
 * It would be possible to reduce the memory consumption by a quarter by using patterns
 * of three bits per "0" or "1", but that would require a lot more processing and
 * memory transfer cycles.
 *
 * Of course, having to encode 24 bit RGB values into 3 32 bits words is a bit of a
 * hassle. To make this a bit simpler from a programming point of view, a pallette
 * with "standard" colour values is provided, together with functions to put these
 * values into the display buffer. If necessary, the user can also opt to generate
 * the necessary encoded values and directly put these into the display buffer.
 *
 * The RGB values must be encoded in 3 consecutive 32 bit words in the right (GRB)
 * order. Each bit of each RGB value byte must be translated in a 4 bit pattern. The
 * storage order of these patterns in the 32 bit words depends on the endianness of
 * the ESP32, and is (for each bit 0..7, with 7 the most significant in the byte):
 * 11110000333322225555444477776666
 */

/*
 * if multiple display units are used they must be strung together first 
 * from left to right, then from top to bottom. UNITWIDTH and UNITHEIGHT
 * is the width and height of a single unit. UNITSWIDE and UNITSHIGH
 * are the number of units in the array
 * The top-left pixel is the start of the complete string and the bottom-
 * right pixel the end.
 */

//default #define for the pin to which the screen is connected
#define LEDSCREENPIN 10
#
 //default #defines for geometry
#define UNITWIDTH 10
#define UNITHEIGHT 20
#define UNITSWIDE 1
#define UNITSHIGH 1

//computed from the above
#define UNITBLOCKSIZE UNITWIDTH * UNITSWIDE * UNITHEIGHT
#define TOTALSIZE UNITBLOCKSIZE * UNITSHIGH
#define LEDSTRINGSIZE TOTALSIZE
#define LEDSTRINGBITS LEDSTRINGSIZE * 24 * 4

// encoded RGB screen memory
DMA_ATTR paletteColour ledDMAbuffer[LEDSTRINGSIZE];

// control structures for the spi interface attached to the led screen
static spi_device_handle_t ledScreenSpiDevice;
static spi_device_interface_config_t ledScreenSpiInterfaceCfg;
static spi_bus_config_t ledScreenSpiBusCfg;
static spi_transaction_t ledScreenSpiTransaction;

// initialize the hardware to drive a screen
void initializeSpiLedScreen(void) {
  ledScreenSpiBusCfg = {
  	.mosi_io_num = LEDSCREENPIN,
  	.miso_io_num = -1,
  	.sclk_io_num = -1,
  	.quadwp_io_num = -1,
  	.quadhd_io_num = -1,
  	.max_transfer_sz = LEDSTRINGBITS
	};
  ledScreenSpiInterfaceCfg = {
    .command_bits = 0,
    .address_bits = 0,
    .mode = 0,
    .clock_speed_hz = 3200000,
  	.spics_io_num = -1,
  	.queue_size = 1 
	};
  ledScreenSpiTransaction = {
    .flags=0,
    .cmd=0,
    .addr=0,
    .length=LEDSTRINGBITS,// in bits
    .rxlength=0,
    .user=(void*)0,
    .tx_buffer=(void *)ledDMAbuffer,
    .rx_buffer=(void*)0
  };

	esp_err_t err;
	err = spi_bus_initialize(SPI2_HOST, &ledScreenSpiBusCfg, SPI_DMA_CH_AUTO);
	ESP_ERROR_CHECK(err);
	err = spi_bus_add_device(SPI2_HOST, &ledScreenSpiInterfaceCfg, &ledScreenSpiDevice);
	ESP_ERROR_CHECK(err);
}

// update the actual screen by sending the data to it
void updateSpiLedScreen(void) {
  esp_err_t err;
  err = spi_device_queue_trans(ledScreenSpiDevice, &ledScreenSpiTransaction,1);
}


/*******************************************************************************************************************
* DRAWSUPPORT section
*******************************************************************************************************************/
// basic routines for drawing stuff on both the board and the screen. internally depends on PALETTESUPPORT and
// BOARDSUPPORT and SPILEDSCREEN. Other sections depend on this

// unless the target is evident, routines have  a "target" which specifies what needs to happen
#define TARGETNONE 0
#define TARGETBOARD 1
#define TARGETSCREEN 2
#define TARGETBOTH 3

// set a single encoded pixel in the WS2812 output array
// the target of this function is implicit
void setEncodedScreenPixel(int8_t x, int8_t y, paletteColour v) {
  // in the display row 0 is the top row, in the game its is the bottom row
  int8_t displayy=BOARDHEIGHT-y-1;
  int8_t displayblock=displayy/UNITHEIGHT; // integer div, rounded down
  int16_t displayindex=displayy % UNITHEIGHT + x * UNITHEIGHT + displayblock * UNITBLOCKSIZE;
  ledDMAbuffer[displayindex]=v;
}

// set a single pixel in the WS2812 output array
// the target of this function is implicit
void setScreenPixel(int8_t x, int8_t y, int8_t v) {
  if (y<BOARDHEIGHT) setEncodedScreenPixel(x,y,standardPalette[v]);
}

// updates the WS2812 data array from the corresponding board array position
// the target of this function is implicit
void renderPixel(int8_t x, int8_t y) {
    if (y<BOARDHEIGHT) setScreenPixel(x, y, board[y][x]);
}

// updates a row of WS2812 data array according to the corresponding row in the board array
// the target of this function is implicit
void renderBoardRow(int8_t r) {
  if ((r<BOARDHEIGHT)&&(r>=0)) { // do not try to render any of the invisible rows
    for (int8_t x=0; x<BOARDWIDTH; x++) {
      setScreenPixel(x,r,board[r][x]);
    }
  }
}

// updates a block of WS2812 data array according to the corresponding block in the board array
// the target of this function is implicit
void renderBoardBlock(int8_t startrow, int8_t endrow) {
  if (startrow<endrow) {
    for (int8_t y=startrow; y<endrow; y++) {
      renderBoardRow(y);
    }
  }
}

// completely updates the WS2812 data array according to the board array
// the target of this function is implicit
void renderBoard(void) {
  for (int8_t y=0;y<BOARDHEIGHT; y++) {
    renderBoardRow(y);
  }
}

// set a single pixel in the board / WS2812 output array
// the target of this function is explicit
void setPixel(int8_t x, int8_t y, int8_t c, uint8_t target) {
  if (target & 1) board[y][x]=c;
  if (target & 2) setScreenPixel(x, y, c);
}

// set a single row in the board / WS2812 output array to a specific colour index
// the target of this function is explicit.
void setPixelRow (int8_t y, int8_t v, uint8_t target) {
  for (int8_t x=0; x<BOARDWIDTH; x++) {
    setPixel(x, y, v, target);
  }
}

// sets a block of rows in the board/WS2812 output array to a specific colour index
// the target of this function is explicit
void setPixelBlock(int8_t startrow, int8_t endrow, int8_t v, uint8_t target){
  for (int8_t i=startrow; i<endrow; i++) setPixelRow(i,v,target);
}

// clears all pixels in the board / WS2812 output array
// the target of this function is explicit
void clearAllPixels(uint8_t target) {
  if (target & 1) {
    for (uint8_t y=0;y<BOARDHEIGHT+SPAWNHEIGHT; y++) {
      for (uint8_t x=0; x<BOARDWIDTH; x++) {
        board[y][x]=0;
      }
    }
  }
  if (target & 2) {
    for (int i=0;i<LEDSTRINGSIZE; i++) {
      ledDMAbuffer[i]=standardPalette[0];
    }
  }
}

// copies a row of pixels. If target includes screen, the copy is made by rendering the board row
// the target of this function is explicit
void copyPixelRow(int8_t fromrow, int8_t torow, uint8_t target) {
  if (target & 1) {
    for (uint8_t x=0; x<BOARDWIDTH; x++) {
      board[torow][x]=board[fromrow][x];
    }
  }
  if (target & 2) {
    for (uint8_t x=0; x<BOARDWIDTH; x++) {
      setScreenPixel(x,torow,board[fromrow][x]);
    }
  }
}

// moves al rows >=endrow toward startrow, backfilling the vacated area with the specified colour v
// the target of this function is explicit
void removePixelRowBlock(int8_t startrow, int8_t endrow, int8_t v, uint8_t target) {
  int8_t nrrows=BOARDHEIGHT+SPAWNHEIGHT-endrow;
  for (uint8_t i=0; i<nrrows; i++) {
    copyPixelRow(endrow+i,startrow+i,target);
  }

  for (uint8_t i=startrow+nrrows; i<BOARDHEIGHT+SPAWNHEIGHT; i++) {
    setPixelRow (i, v, target);
  }
}


/*******************************************************************************************************************
* BLOCKSSUPPORT section
*******************************************************************************************************************/
// routines for working with "falling" blocks. Depends on everything above

// every shape can be in 4 different orentations
// 0 - the spawn orientation
// 1 - rotated 90 degrees counter-clockwise (also known as "L")
// 2 - rotated bij 180 degrees (also known as "2")
// 3 - rotated 90 degrees clockwise (also known as "R")

/*
 *Shapes drawn in 4x4 boxes in different orientations 0 - 1 - 2 - 3 
 * The "centre" of the box is always at the same position:
 * ....
 * .c..
 * ....
 * ....
 * note that in case of I the "centre" can be OUTSIDE the piece itself
 *
 *  .... .#.. .... ..#.     .... .... .... ....
 *  #### .#.. .... ..#.     .##. .##. .##. .##.
 *  .... .#.. #### ..#.     .##. .##. .##. .##.
 *  .... .#.. .... ..#.     .... .... .... ....
 *
 *  .#.. .#.. .... .#..
 *  ###, ##.. ###. .##.
 *  .... .#.. .#.. .#..
 *  .... .... .... ....
 *
 *  ..#. ##,, .... .#..     #... .#.. .... .##.
 *  ###. .#.. ###. .#..     ###. .#.. ###. .#..
 *  .... .#.. #... .##.     .... ##.. ..#. .#..
 *  .... .... .... ....     .... .... .... ....
 *
 *  .##. #... .... .#..     ##.. .#.. .... ..#.
 *  ##.. ##.. .##. .##.     .##. ##.. ##.. .##.
 *  .... .#.. ##.. ..#.     .... #... .##. .#..
 *  .... .... .... ....     .... .... .... ....
 */

// every shape has a number, and the correct colour is this number * 2 (+1 if extra bright)
#define SHAPE_I 1
#define SHAPE_O 2
#define SHAPE_T 3
#define SHAPE_L 4
#define SHAPE_J 5
#define SHAPE_S 6
#define SHAPE_Z 7

// kick data for the I shape
kick Ikickdata[8][5] = {
  { {0,0},{-2,0},{1,0},{-2,-1},{1,2} },//(0->R)
  { {0,0},{-1,0},{2,0},{-1,2},{2,-1} },//(0->L)
  { {0,0},{1,0},{-2,0},{1,-2},{-2,1} },//(L->0)
  { {0,0},{-2,0},{1,0},{-2,-1},{1,2} },//(L->2)
  { {0,0},{2,0},{-1,0},{2,1},{-1,-2} },//(2->L)
  { {0,0},{1,0},{-2,0},{1,-2},{-2,1} },//(2->R)
  { {0,0},{-1,0},{2,0},{-1,2},{2,-1} },//(R->2)
  { {0,0},{2,0},{-1,0},{2,1},{-1,-2} } //(R->0)
};
// kick data for other shapes
kick Okickdata[8][5] = {
  { {0,0},{-1,0},{-1,1},{0,-2},{-1,-2} },//(0->R)
  { {0,0},{1,0},{1,1},{0,-2},{1,-2} },//(0->L)
  { {0,0},{-1,0},{-1,-1},{0,2},{-1,2} },//(L->0)
  { {0,0},{-1,0},{-1,-1},{0,2},{-1,2} },//(L->2)
  { {0,0},{1,0},{1,1},{0,-2},{1,-2} },//(2->L)
  { {0,0},{-1,0},{-1,1},{0,-2},{-1,-2} },//(2->R)
  { {0,0},{1,0},{1,-1},{0,2},{1,2} },//(R->2)
  { {0,0},{1,0},{1,-1},{0,2},{1,2} } //(R->0)
};
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
void loop() {
  switch (gameState) {
    case 0: doGameState0(); break;
    case 1: doGameState1(); break;
    case 2: doGameState2(); break;
  }
  if ((millis()-lastScreenUpdate)>=25) {
    updateSpiLedScreen();
    lastScreenUpdate=millis();
  }
}

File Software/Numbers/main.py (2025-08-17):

from neopixel import NeoPixel
from time import sleep_ms
from machine import Pin
import random

i = 0

r = 22
g = 2
b = 2

ms = 50

p = Pin(10, Pin.OUT)
np = NeoPixel(p, 200)
np.fill((0,0,0))
np.write()

def num_1():
 c = 4 * 20
 for i in range(20):
  np[i+c] = (r,g,b)
 c = 5 * 20
 for i in range(20):
  np[i+c] = (r,g,b)

 for i in range(10):
  c = i * 20
  for x in range(18,20):
   np[x+c] = (r,g,b)

 np[23] = (r,g,b)
 np[24] = (r,g,b)

 np[42] = (r,g,b)
 np[43] = (r,g,b)

 np[61] = (r,g,b)
 np[62] = (r,g,b)

num_1()
np.write()


#second_clock()

def rand_pixel():
 return (random.randint(0,r), random.randint(0,g),  random.randint(0,b))

def cykel_pixel():
 global i
 np.fill((0,0,0))
 np[i] = rand_pixel()
 np.write()
 i = i + 1
 if i > 199:
  i = 0

def test(ms=2):
 for x in range(200):
  np.fill((0,0,0))
  np[x] = (r,g,b)
  np.write()
  sleep_ms(10)

def second_clock():
 while 1:
  cykel_pixel()
  sleep_ms(ms)
